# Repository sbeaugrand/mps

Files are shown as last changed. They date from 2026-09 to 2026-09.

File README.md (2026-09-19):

# Build
```sh
make docker-help  # :
```
```sh
docker build -f Dockerfile.armhf -t debian-armhf .
docker build -f Dockerfile.arm64 -t debian-arm64 .
make docker-make XC=arm-linux-gnueabihf
make docker-make XC=aarch64-linux-gnu
make docker-package XC=arm-linux-gnueabihf
make docker-package XC=aarch64-linux-gnu
```
## Comparison between jsonrpccpp and json-rpc-cxx
json-rpc-cxx:
- compile time x2
- binary size x3

# Readme from
https://github.com/sbeaugrand/debinst/tree/master/cicd/mps
```sh
make help  # :
```

## Create chroot
<details>
  <summary>Create chroot</summary>

  ```console
  localhost> cd ../hosts/debian13
  localhost> make up
  localhost> make add-ip
  localhost> vagrant halt
  localhost> make up
  localhost> vagrant provision
  localhost> make ssh-copy-id  # for rsync in sbuild.yml
  localhost> vagrant ssh
   vagrant1> mkdir ~/sbuild
   vagrant1> sudo mkdir /temp && sudo chmod 777 /temp
   vagrant1> export TMPDIR=/temp
   vagrant1> DIST=stable
   vagrant1> ARCH=armhf  # nanopi-neo:armhf orange-pi-zero:armhf rockpi-s:arm64
   vagrant1> mmdebstrap --variant=buildd --architectures=$ARCH $DIST ~/sbuild/$DIST-$ARCH.tar.xz --include=cmake,debhelper,fakeroot,help2man,pkg-config,lintian,dose-distcheck,apt-utils,libargtable2-dev,libcurl4-openssl-dev,libjsoncpp-dev,libmicrohttpd-dev,libmpdclient-dev,liblirc-dev,swig,python3-dev
  ```
</details>

## Build libs
[libjsonrpccpp](../libjsonrpccpp/README.md)

[libmraa](../libmraa/README.md)

[libupm](../libupm/README.md)

## Release
```console
 vagrant1> sudo apt install libmpdclient-dev liblirc-dev
localhost> make BUILDER=sbuild rbuild
localhost> make BUILDER=sbuild rpackage
localhost> make BUILDER=sbuild rxpackage OPTS='-e ARCH=armhf'
```

# Cross build

<details>
  <summary>Method 1: sysroot from remote</summary>

  ## Install libs
  ```console
  localhost> cd ../hosts/debian13
  localhost> vagrant ssh
   vagrant1> cp sbuild/*.deb /vagrant/.vagrant/
   vagrant1> rm -f /vagrant/.vagrant/*dbgsym*.deb
  localhost> user=$USER
  localhost> host=pi
  localhost> scp .vagrant/*.deb $user@$host:/tmp/
  localhost> ssh $user@$host
   remotepi> cd /tmp
   remotepi> sudo apt reinstall ./*.deb
   remotepi> sudo apt install libmpdclient-dev liblirc-dev gcc g++
   remotepi> sudo apt install libgpiod-dev  # optional ds1302 rtc
  ```
  ## Create sysroot
  ```console
  localhost> cd ~/data/tmp
  localhost> mkdir aarch64-linux-gnu-14 && cd aarch64-linux-gnu-14  # or :
  localhost> mkdir arm-linux-gnueabihf-14 && cd arm-linux-gnueabihf-14
  localhost> mkdir usr
  localhost> user=$USER
  localhost> host=pi
  localhost> rsync -a -i --delete --checksum $user@$host:/usr/include usr/
  localhost> rsync -a -i --delete --checksum $user@$host:/usr/lib usr/
  localhost> rsync -a -i --delete --checksum $user@$host:/lib ./
  localhost> sudo ln -sfn ~/data/tmp/aarch64-linux-gnu-14 /usr/gnemul/qemu-aarch64  # or:
  localhost> sudo ln -sfn ~/data/tmp/arm-linux-gnueabihf-14 /usr/gnemul/qemu-arm
  ```
  ## Optional VM sysroot
  ```console
  localhost> cd ../hosts/debian13
  localhost> rsync -a -i --delete --checksum ~/data/tmp/aarch64-linux-gnu-14 .vagrant/  # or :
  localhost> rsync -a -i --delete --checksum ~/data/tmp/arm-linux-gnueabihf-14 .vagrant/
  ```
</details>

<details>
  <summary>Method 2: sysroot from mmdebstrap</summary>

  ```console
   vagrant1> DIST=stable
   vagrant1> ARCH=armhf  # nanopi-neo:armhf orange-pi-zero:armhf rockpi-s:arm64
   vagrant1> cd ~/sbuild
   vagrant1> mkdir -p ../pbuilder
   vagrant1> xz -d -c $DIST-$ARCH.tar.xz | gzip >../pbuilder/$DIST-$ARCH-base.tgz
   vagrant1> python3 -m http.server
   vagrant2> DIST=stable
   vagrant2> ARCH=armhf  # nanopi-neo:armhf orange-pi-zero:armhf rockpi-s:arm64
   vagrant2> SYSROOT=arm-linux-gnueabihf-14  # aarch64-linux-gnu-
   vagrant2> cd ~/sbuild
   vagrant2> dpkg-scanpackages . /dev/null >Packages
   vagrant2> pbuilder-dist $DIST $ARCH update --extrapackages 'libjsonrpccpp-common0 libjsonrpccpp-client0 libjsonrpccpp-stub0 libjsonrpccpp-server0 libjsonrpccpp-dev libmraa2 libmraa-dev libupm-lcd2 libupm-dev' --allow-untrusted --othermirror 'deb [allow-insecure=yes] http://localhost:8000/ ./'
   vagrant2> cd ../pbuilder
   vagrant2> export TMPDIR=/temp
   vagrant2> mmdebstrap --variant=custom --architectures=$ARCH --skip=update,setup,cleanup,tar-in/mknod --setup-hook="tar-in $DIST-$ARCH-base.tgz /" --customize-hook="copy-out /usr/include /vagrant/.vagrant/$SYSROOT/usr/" $DIST /dev/null
   vagrant2> mmdebstrap --variant=custom --architectures=$ARCH --skip=update,setup,cleanup,tar-in/mknod --setup-hook="tar-in $DIST-$ARCH-base.tgz /" --customize-hook="copy-out /usr/lib /vagrant/.vagrant/$SYSROOT/usr/" $DIST /dev/null
  localhost> SYSROOT=arm-linux-gnueabihf-14  # aarch64-linux-gnu-
  localhost> cd .vagrant/$SYSROOT
  localhost> ln -s usr/lib
  localhost> cp -a ../$SYSROOT ~/data/tmp
  ```
</details>

```sh
make xbuild
make xpackage
make xdeploy
```
```sh
make reinstall
```

# Structure of album directories
`music_directory/additional_directory/artist - year - album/00.m3u`

`music_directory` :
from /etc/mpd.conf

`additional_directory` :
to use weights in random selection of albums,
weights will be in music_directory/mps.weights

# [Client state diagram](README-0.md)
```mermaid
stateDiagram
    direction LR
    [*] --> Normal
    Normal --> Normal: setup / ok / up / down / right
    Normal --> Album: left
    Album --> Normal: ok
    Album --> Album: up / down
    Album --> Artist: left
    Artist --> Album: setup
    Artist --> Artist: letter
```

# [Screensaver state diagram](README-0.md)
```mermaid
stateDiagram
    direction LR
    [*] --> Normal
    Normal --> Menu: ok
    Menu --> Normal: ok = cancel
    Menu --> Normal: right = /usr/bin/rtc
    Menu --> [*]: up = reboot / down = halt
    Menu --> Date: left
    Date --> Date: dir
    Date --> Hour: ok
    Hour --> Hour: dir
    Hour --> Menu: ok
```

# [Main sequence diagram](README-0.md)
```mermaid
sequenceDiagram
    Participant U as User
    Participant C as Client
    Participant S as Server
    loop
        U->>C: event "setup"
        activate C
        C->>+S: call "rand"
        S-->>-C: album
        deactivate C
    end
    Note over U,S: Less than 20 seconds
    U->>C: event "ok"
    activate C
    C->>+S: call "ok"
    S-->>-C: album
    C->>+S: call "checksum"
    S-->>-C: album
    deactivate C
```

# Divers

<details>
  <summary>Test without arm</summary>

  ```console
  terminal1> make build
  terminal1> make server
  terminal2> make client  # KEY_SETUP, KEY_OK, ...
  terminal3> make dir path=
  terminal3> ./client.py
  terminal3> ./client.py [method]  # rand, ok, ...
  terminal3> ./client.py quit
  ```
</details>

<details>
  <summary>php usage</summary>

  ```console
  terminal1> make tunnel
  terminal2> make php
  ```
</details>

<details>
  <summary>music_directory update</summary>

  ```sh
  mpc update
  rm mps.list
  sudo systemctl restart mpserver
  ```
</details>

<details>
  <summary>manpages update</summary>

  ```sh
  make
  cp build/*.1 .
  ```
</details>

<details>
  <summary>No apt list update</summary>

  ```sh
  sudo mv /etc/apt/apt.conf.d/02-armbian-postupdate ~/
  ```
</details>

<details>
  <summary>mpc usage for debug</summary>

  ```sh
  mpc clear
  mpc load '<[inside_music_directory]>/00.m3u'
  mpc play
  ```
</details>

[gitlab](../hosts/gitlab/README.md)

[forgejo](../hosts/forgejo/README.md)

# BOM 2021
[pdf](http://beaugrand.chez.com/pdf/remoteControl.pdf)

# BOM 2025
|Article|TTC|Nombre|Total|
|---|-----:|:-----:|-----:|
|[Platine sans cuivre 100x160mm](https://www.conrad.fr/fr/search.html?search=529569) |  3.99|1 |  3.99|
|[Connecteur femelle pour CI 32 contacts](https://fr.rs-online.com/web/p/connecteurs-femelles-pour-ci/1803928)| 19.00|39/32/5|  4.63|
|[Barrette mâle 40 pôles 12.50](https://www.conrad.fr/fr/search.html?search=1390110) |  3.80|1/5 |  0.76|
|[Barrette femelle 20 pôles coudée](https://www.conrad.fr/fr/search.html?search=1560681) |  3.99|15/20  |  2.99|
|[Barrette femelle 36 pôles droite](https://www.conrad.fr/fr/search.html?search=1560794) |  4.29|22/36  |  2.62|
|[Connecteur USB mâle coudé](https://www.conrad.fr/fr/search.html?search=1567163) |  3.29|1 |  3.29|
|[Connecteur USB femelle coudé](https://www.conrad.fr/fr/search.html?search=1567164) |  3.29|1 |  3.29|
|[Entretoise M3 25mm acier galvanisé](https://www.conrad.fr/fr/search.html?search=521678) |  2.99|4/10 |  1.20|
|[Entretoise M3 15mm Polyamide](https://www.conrad.fr/fr/search.html?search=2163259) |  3.08|2/7 |  0.88|
|[Vis M3 6mm Polyamide](https://www.conrad.fr/fr/search.html?search=1817006) |  9.99|8/200  |  0.40|
|[Module RTC](https://www.conrad.fr/fr/search.html?search=2481842) |  9.99|1/2 |  5.00|
|[Récepteur infrarouge 1838](https://www.conrad.fr/fr/search.html?search=1572283) |  1.79|1/2 |  0.90|
|[Télécommande IRC01](https://www.gotronic.fr/art-telecommande-ir-irc01-19568.htm) |  2.90|1 |  2.90|
|[Embase d'alimentation 2.1mm 5.5mm](https://www.conrad.fr/fr/search.html?search=735754) |  1.84|1/2 |  0.92|
|[Bloc d'alimentation 12V 1A](https://www.conrad.fr/fr/search.html?search=3397133) | 10.99|1 | 10.99|
|[Carte SD A1](https://fr.rs-online.com/web/p/cartes-sd/2836581) | 11.68|1 | 11.68|
|[Condensateur 1000uF 16V 10x16mm](https://www.conrad.fr/fr/search.html?search=443933) |  4.00|2/20 |  0.40|
|[Interrupteur à levier 2 x On/On](https://www.conrad.fr/fr/search.html?search=1589399) |  1.99|2 |  3.98|
|[Patte d'assemblage 100x15x2mm](https://www.bricorama.fr/search?q=3274590517126) |  1.10|3 |  3.30|
|[Patte d'assemblage 60x15x2mm](https://www.bricorama.fr/search?q=3274590517102) |  1.10|4 |  4.40|
|[Charnière 40x25mm entraxe 27mm](https://www.bricorama.fr/search?q=3505391042136) |  5.40|1/2 |  2.70|
|[NanoPi NEO-LTS soldered](https://fr.aliexpress.com/item/1005005383857521.html) | 21.55|1 | 21.55|
|[Ampli XH-M567 TPA3116D2](https://fr.aliexpress.com/item/1005004830515523.html) |  3.39|1 |  3.39|
|[Régulateur de tension LM2596](https://fr.aliexpress.com/item/1005005970782265.html) |  1.32|1 |  1.32|
|[OLED blanc 1.3 i2c gnd](https://fr.aliexpress.com/item/1005006862867338.html) |  2.42|1 |  2.42|
|==Total== |146.66| | 99.89|
|**Alternative**|**TTC**|**Nombre**|**Total**|
|[NanoPi NEO2](https://fr.aliexpress.com/item/1005008828046430.html) | 38.88|1 | 38.88|
|[Connecteur femelle pour CI 36 contacts](https://fr.rs-online.com/web/p/connecteurs-femelles-pour-ci/5490026)| 34.23|8/36/5 |  1.52|
|[Entretoise filetée 15mm](https://fr.rs-online.com/web/p/entretoises-filetees/1026378) |  6.43|4/10 |  2.57|
|[Vis à tête Cylindrique Cruciforme M3 8mm](https://fr.rs-online.com/web/p/vis-a-metaux/1854437) |  5.02|8/20 |  2.01|

# License CeCILL 2.1

Copyright Sébastien Beaugrand

This software is governed by the CeCILL license under French law and
abiding by the rules of distribution of free software. You can use,
modify and/or redistribute the software under the terms of the CeCILL
license as circulated by CEA, CNRS and INRIA at the following URL
"http://www.cecill.info".

As a counterpart to the access to the source code and rights to copy,
modify and redistribute granted by the license, users are provided only
with a limited warranty and the software's author, the holder of the
economic rights, and the successive licensors have only limited
liability.

In this respect, the user's attention is drawn to the risks associated
with loading, using, modifying and/or developing or reproducing the
software by the user in light of its specific status of free software,
that may mean that it is complicated to manipulate, and that also
therefore means that it is reserved for developers and experienced
professionals having in-depth computer knowledge. Users are therefore
encouraged to load and test the software's suitability as regards their
requirements in conditions enabling the security of their systems and/or
data to be ensured and, more generally, to use and operate it in the
same conditions as regards security.

The fact that you are presently reading this means that you have had
knowledge of the CeCILL license and that you accept its terms.

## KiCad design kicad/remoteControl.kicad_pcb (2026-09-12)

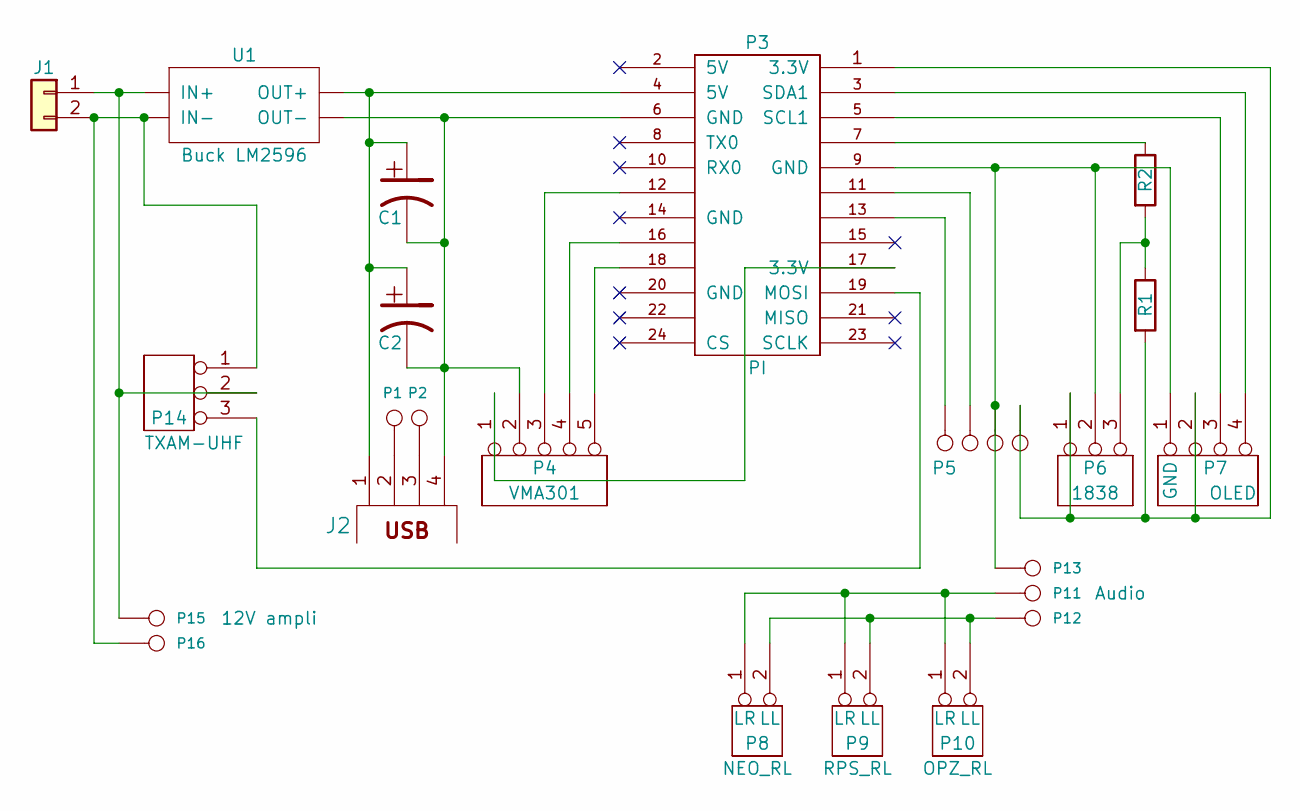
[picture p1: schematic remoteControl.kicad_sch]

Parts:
C1, C2: CP1; CP2
J1: Conn_01x02; BarrelJack_Horizontal
J2: USB_2; PIN_ARRAY_4X1
P1, P2, P5, P11, P12, P13, P15, P16, P17, P18, P19: CONN_1; PIN_ARRAY_1X1
P3: PI
P4: CONN_5; VMA301
P6, P14: CONN_3; PIN_ARRAY_3X1
P7: CONN_4X1; PIN_ARRAY_4X1
P8, P9, P10: CONN_2; PIN_ARRAY_2X1
R1, R2: R; R3
U1: BUCK

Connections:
unnamed: J1.1, P14.2, P15.1, U1.1 (IN+)
unnamed: J1.2, P14.1, P16.1, U1.2 (IN-)
unnamed: J2.2, P1.1
unnamed: J2.3, P2.1
unnamed: P3.7, R2.1
unnamed: P3.13, P5.1
unnamed: P3.5 (SCL1), P7.3
unnamed: P3.3 (SDA1), P7.4
unnamed: P3.17 (3.3V), P4.1
unnamed: C1.2, C2.2, J2.4, P3.6 (GND), P4.2, U1.4 (OUT-)
unnamed: P3.12, P4.3
unnamed: P3.16, P4.4
unnamed: P3.18, P4.5
unnamed: P3.1 (3.3V), P6.1, P7.2, P19.1, R1.2
unnamed: P3.9 (GND), P6.2, P7.1, P13.1, P18.1
unnamed: P6.3, R1.1, R2.2
unnamed: P8.1, P9.1, P10.1, P11.1
unnamed: P8.2, P9.2, P10.2, P12.1
unnamed: P3.19 (MOSI), P14.3
unnamed: P3.11, P17.1
unnamed: C1.1, C2.1, J2.1, P3.4 (5V), U1.3 (OUT+)

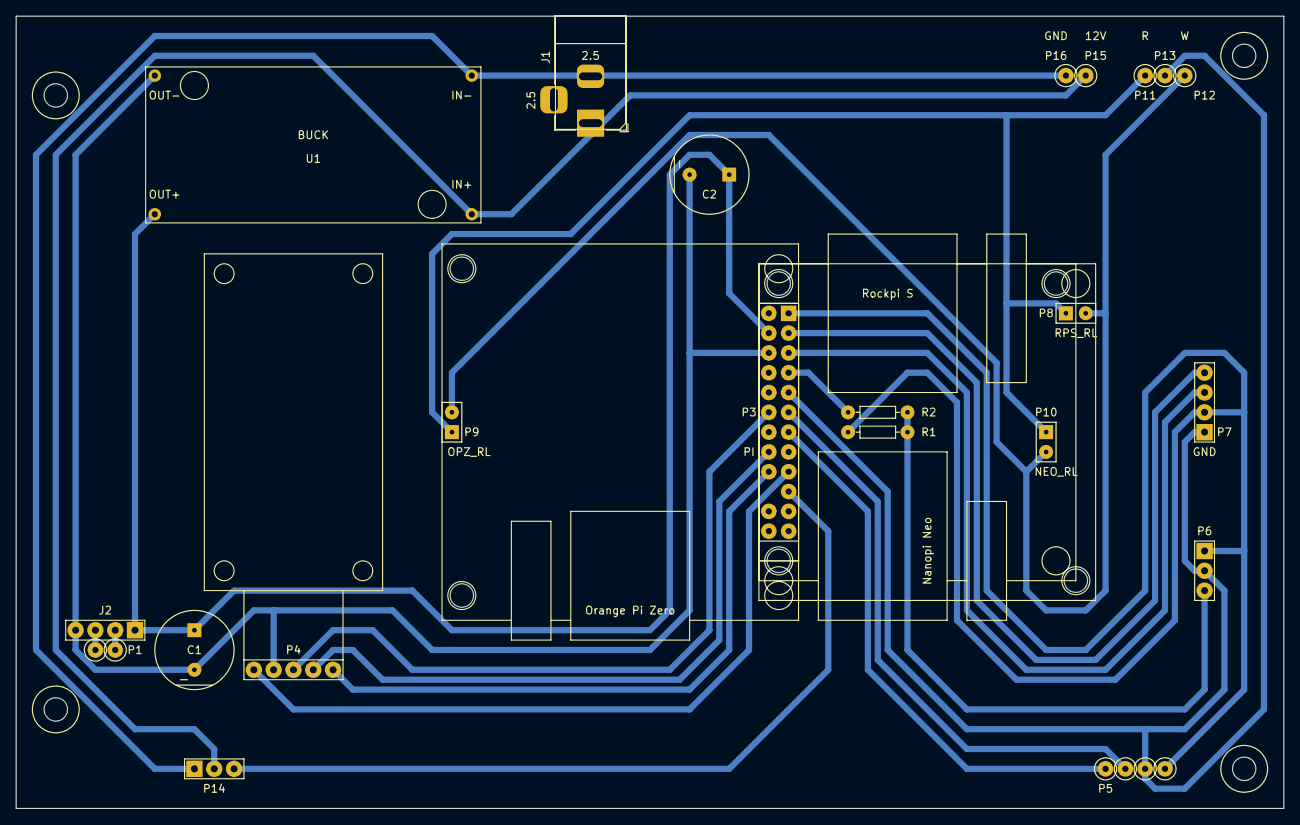
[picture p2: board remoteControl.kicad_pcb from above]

Board: 2 copper layers, 162.6 x 101.6 mm, 27 parts (0 on the bottom side), 21 nets.

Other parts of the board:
GR**: PLATINE_160x100

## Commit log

2026-09-12 first commit from https://github.com/sbeaugrand/debinst/tree/master/cicd/mps
    [lifiEmitter.kicad_pcb, lifiEmitter.kicad_sch, lifiReceiver.kicad_pcb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]
2026-09-15 build: submodules
    [lifiEmitter.kicad_pcb, lifiEmitter.kicad_sch, lifiReceiver.kicad_pcb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]
2026-10-19 feat(makefiles): arm docker base
